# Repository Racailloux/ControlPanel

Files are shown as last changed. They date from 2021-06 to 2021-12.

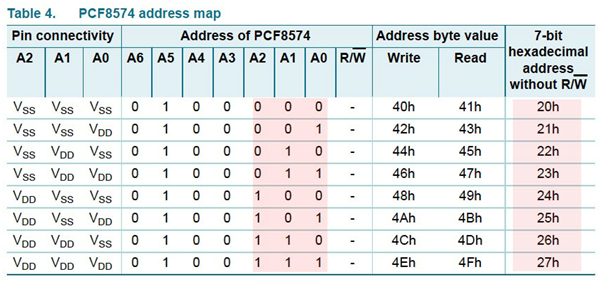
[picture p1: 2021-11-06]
Arduino/PCF8574_Addressing.png

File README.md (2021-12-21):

# Black Otters Control Panel






<br><br>
[French Section Française](#french-section) - 
[English English Section](#english-section)
<br><br>

<p align="center">Control Panel</p>

# French section

## Introduction

Ceci est un projet de panneau de contrôle personnalisé développé pour la corporation de la [Black Otters](https://www.blackotters-corporation.com/) du jeu [Star Citizen](https://robertsspaceindustries.com/star-citizen).

## Contenu

### Boitier imprimé 3D
* Modèles en 3D au format Fusion 360
* Fichiers STL exportés en STL

### Contrôles
Multiples contrôles optimisés pour l'utilisation dans Star Citizen (multi rôles : Vol, Combat & Minage)
* 1 Axe pour la puissance du minage
* 1 codeur pour encoder for le niveau des gaz
* 39 Boutons :
  * Boutons rétroéclairés par LEDs avec la luminosité ajustable (le potentiomètre sur la droite du boitier contrôle la luminosité)
  * Code couleur des boutons : Rouge : Urgencesy / Jaune : Changement de mode / Blanc : Réinitialisation / Vert : Boutons spéciaux / Bleu : Boutons standards

### Autocollant
Un autocollant modèle au format SVG pour placer sous les contrôles sur la façade avant : Textes, logo, ...

### Logiciel
Programme pour Arduino Micro relié à 5 modules d'extension PCF8574
* Mode Joystick contrôlé par USB
* Gestion de l'axe et du codeur
* Entrée analogique pour contrôler l'éclairage  des LEDs en PWM

### Association des contrôles pour Star Citizen
 * Fichier d'association (Layout) des contrôles pour l'importation dans Star Citizen (Utile pour les utilisateurs au clavier/souris, La gestion de multiple joysticks nécessitant une configuration adaptée)

## Credits

### Libraires Arduino

[Libraire Joystick](https://github.com/MHeironimus/ArduinoJoystickLibrary) : Libraire Arduino pour simuler le comportement d'un Joystick .<br>
[Libraire PCF8574](https://github.com/xreef/PCF8574_library) : Libraire Arduino pour gérer les puces PCF8574.<br>

### Sources d'inspiration

[Custom Starcitizen control panels](https://robertsspaceindustries.com/community/citizen-spotlight/3330-Custom-Starcitizen-Control-Panels)<br>
[Star Citizen Custom Controller](https://shinythinks.com/project/star-citizen-custom-controller/)<br>
[MAXED - Custom Star Citizen hardware. mk1 prototype](https://www.reddit.com/r/starcitizen/comments/9jc5qt/maxed_custom_star_citizen_hardware_mk1_prototype/)<br>

# English section

## Introduction

This is a project for custom Control Panel developped for [Black Otters](https://www.blackotters-corporation.com/) corporation in the [Star Citizen](https://robertsspaceindustries.com/star-citizen) game.

## Contents

### 3D printed case
* Fusion 360 3D models
* Exported files in STL

### Controls
Multiple controls optimized for Star Citizen usage (multi roles : Flight, Fight & Mining)
* 1 Axis for mining power
* 1 encoder for Throttle
* 39 Buttons :
  * Backlight with led power adjustable (potentiometer on the right of the case controls the LEDs power)
  * color coded buttons : Red : Emergency / Yellow : Mode change / White : Reset / Green : Special buttons / Blue : Standard buttons

### Sticker
Template sticker in SVG to be placed below front panel controls : Texts, logo, ...

### Software
Program of arduino Micro with 5 extension PCF8574 modules
* USB Controlled Joystick mode
* Encoder & Axis management
* Analog input to control PWM lighting level of LEDs

### Star Citizen Layout
 * Layout of the control panel to be imported in Star Citizen (for keyboard/mouse users only, multiple joysticks need a specific configuration)

## Credits

### Arduino Libraries

[Joystick Library](https://github.com/MHeironimus/ArduinoJoystickLibrary) : Arduino library to simulate a Joystick behavior.<br>
[PCF8574 Library](https://github.com/xreef/PCF8574_library) : Arduino Library to manage PCF8574 chipset.<br>
[Tools40](https://github.com/IndustrialShields/arduino-Tools40) : Arduino libraries used for debounce features.<br>

### Inspiration sources

[Custom Starcitizen control panels](https://robertsspaceindustries.com/community/citizen-spotlight/3330-Custom-Starcitizen-Control-Panels)<br>
[Star Citizen Custom Controller](https://shinythinks.com/project/star-citizen-custom-controller/)<br>
[MAXED - Custom Star Citizen hardware. mk1 prototype](https://www.reddit.com/r/starcitizen/comments/9jc5qt/maxed_custom_star_citizen_hardware_mk1_prototype/)<br>

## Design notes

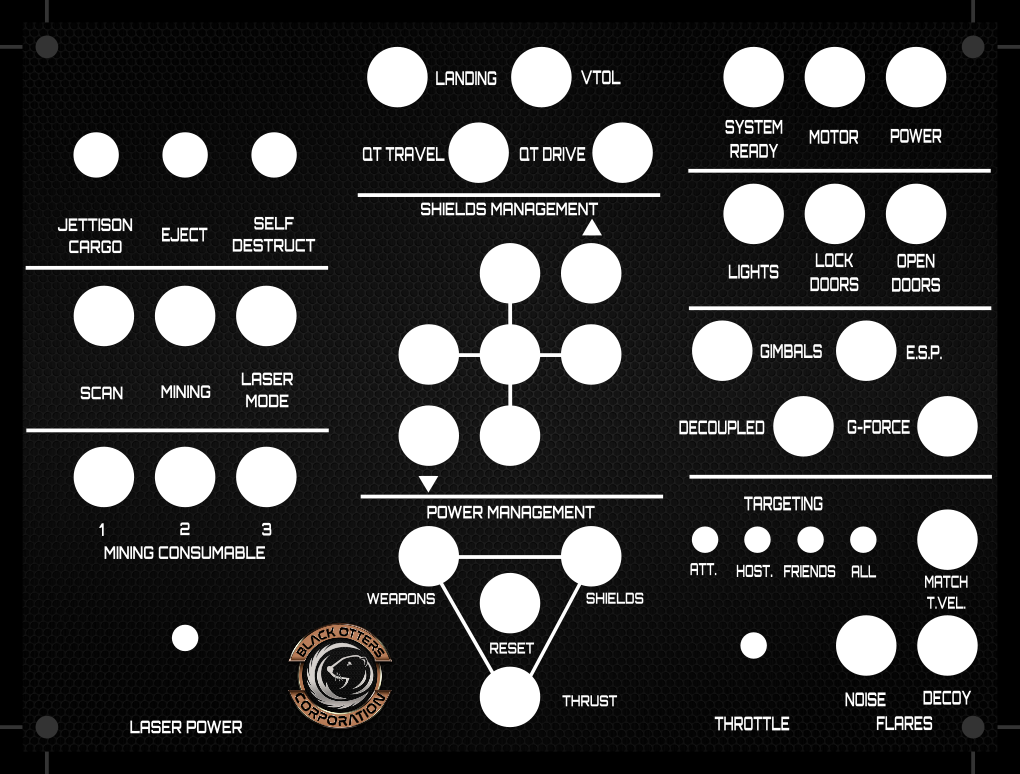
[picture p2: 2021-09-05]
Front Sticker/Front Sticker.png

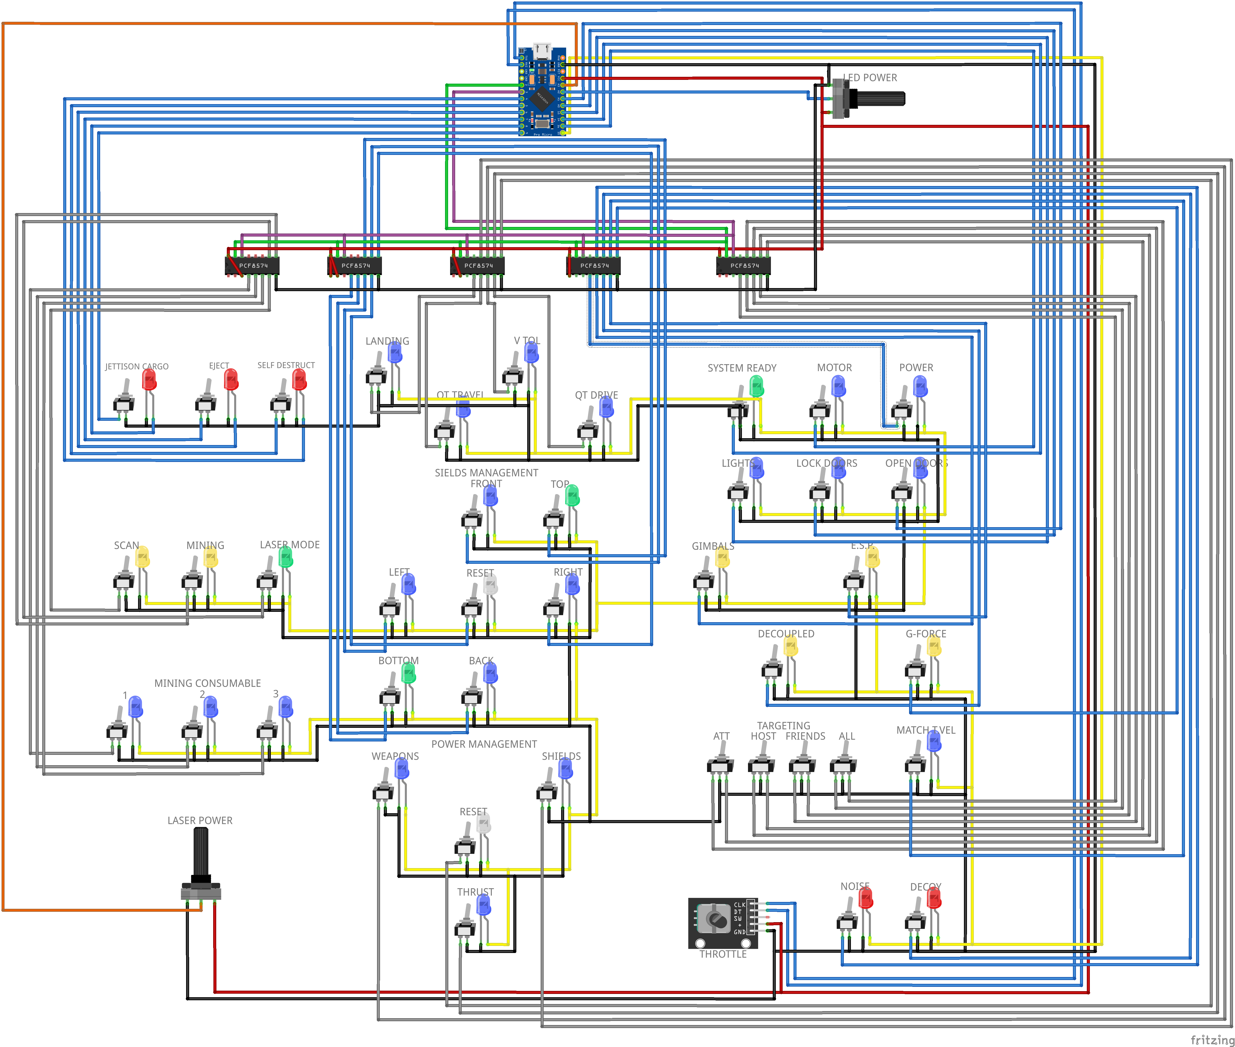
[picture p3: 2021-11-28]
Electrical diagrams/Electrical diagrams.png

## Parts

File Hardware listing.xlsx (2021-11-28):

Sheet: Nomenclature FR
Produits | Référence | Prix Unitaire | Quantité | Ports | Prix Total
Arduino micro | AliExpress (https://fr.aliexpress.com/item/1348800135.html) | 3.37 € | 1 | 2.50 € | 5.87 €
Carte d'extension PCF8574 | AliExpress (https://fr.aliexpress.com/item/32353277284.html) | 0.60 € | 5 | 2.85 € | 5.85 €
Bouton poussoir métal illuminé Bleu 16mm | AliExpress (https://fr.aliexpress.com/item/32972808322.html) | 0.95 € | 20 | 5.00 € | 24.00 €
Bouton poussoir métal illuminé Blanc 16mm | AliExpress | 0.95 € | 2 | 2.57 € | 4.47 €
Bouton poussoir métal illuminé Vert 16mm | AliExpress | 0.95 € | 4 | 2.84 € | 6.64 €
Bouton poussoir métal illuminé Jaune 16mm | AliExpress | 0.95 € | 6 | 3.14 € | 8.84 €
Bouton poussoir métal illuminé Rouge 16mm | AliExpress | 0.95 € | 2 | 2.57 € | 4.47 €
Inter (on)-off-(on) | AliExpress (https://fr.aliexpress.com/item/4000512396094.html) | 0.95 € | 4 | 2.54 € | 6.34 €
Interrupteur à capot | AliExpress (https://fr.aliexpress.com/item/32830627397.html) | 1.39 € | 3 | 4.11 € | 8.28 €
Codeur rotatif | AliExpress (https://fr.aliexpress.com/item/33041814942.html) | 0.38 € | 1 | 3.26 € | 3.64 €
Potentiomètre 10k | AliExpress | 0.56 € | 2 | 0.00 € | 1.12 €
Bouton potentiomètre 25mm (codeur) | AliExpress (https://fr.aliexpress.com/item/32749196628.html) | 1.48 € | 1 | 1.23 € | 2.71 €
Bouton potentiomètre 29mm (potentiomètre) | AliExpress (https://fr.aliexpress.com/item/32919900747.html) | 0.31 € | 1 | 1.12 € | 1.43 €
Câbles dupont 40cm F2F | AliExpress (https://fr.aliexpress.com/item/32965923603.html) | 1.56 € | 2 | 2.39 € | 5.51 €
Fil 22AWG | Amazon (https://www.amazon.fr/dp/B08BPBPBWT/) | 0.28 € | 8 | 0.00 € | 2.27 €
Filament PLA noir | SOVB3D (https://www.sovb3d.fr/pla-175mm-standard-1kg/108-fil-pla-noir-175mm-1kg.html) | 25.45 € | 0.5 |  | 12.72 €
Vis M3 x8mm | Aliexpress (https://fr.aliexpress.com/item/32810872544.html) | 0.02 € | 8 | 1.77 € | 1.93 €
Vis M3 x12mm | Aliexpress | 0.08 € | 8 | 1.77 € | 2.40 €
Autocollant | Amazon (https://www.amazon.fr/dp/B00PFW4K7C/) | 2.00 € | 1 |  | 2.00 €
Encre | Amazon (https://www.amazon.fr/dp/B000NOSAXW/) | 23.99 € | 0.5 |  | 11.99 €
Laque brillante | Amazon (https://www.amazon.fr/gp/product/B00AF09NK8/) | 11.50 € | 0.05 |  | 0.58 €
Antidérapants | Amazon (https://www.amazon.fr/dp/B07C9XKDDK/) | 0.21 € | 4 |  | 0.84 €
 |  |  |  | TOTAL (est.) | 123.90 €

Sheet: Nomenclature EN
Protduct | Reference | Unit price | Quantity | Shipping | Total price
Arduino micro | AliExpress (https://fr.aliexpress.com/item/1348800135.html) | 3.37 € | 1 | 2.50 € | 5.87 €
PCF8574 extension board | AliExpress (https://fr.aliexpress.com/item/32353277284.html) | 0.60 € | 5 | 2.85 € | 5.85 €
Illuminated metal pushbutton Blue 16mm | AliExpress (https://fr.aliexpress.com/item/32972808322.html) | 0.95 € | 20 | 5.00 € | 24.00 €
Illuminated metal pushbutton White 16mm | AliExpress | 0.95 € | 2 | 2.57 € | 4.47 €
Illuminated metal pushbutton Green 16mm | AliExpress | 0.95 € | 4 | 2.84 € | 6.64 €
Illuminated metal pushbutton Yellow 16mm | AliExpress | 0.95 € | 6 | 3.14 € | 8.84 €
Illuminated metal pushbutton Red 16mm | AliExpress | 0.95 € | 2 | 2.57 € | 4.47 €
Inter (on)-off-(on) | AliExpress (https://fr.aliexpress.com/item/4000512396094.html) | 0.95 € | 4 | 2.54 € | 6.34 €
Protected switch | AliExpress (https://fr.aliexpress.com/item/32830627397.html) | 1.39 € | 3 | 4.11 € | 8.28 €
Codeur rotatif | AliExpress (https://fr.aliexpress.com/item/33041814942.html) | 0.38 € | 1 | 3.26 € | 3.64 €
Potentiometer 10k | AliExpress | 0.56 € | 2 | 0.00 € | 1.12 €
Potentiometer button 25mm (encoder) | AliExpress (https://fr.aliexpress.com/item/32749196628.html) | 1.48 € | 1 | 1.23 € | 2.71 €
Potentiometer button 29mm (potentiometer) | AliExpress (https://fr.aliexpress.com/item/32919900747.html) | 0.31 € | 1 | 1.12 € | 1.43 €
Dupont cables 40cm F2F | AliExpress (https://fr.aliexpress.com/item/32965923603.html) | 1.56 € | 2 | 2.39 € | 5.51 €
22AWG wires | Amazon (https://www.amazon.fr/dp/B08BPBPBWT/) | 0.28 € | 8 | 0.00 € | 2.27 €
black PLA filament | SOVB3D (https://www.sovb3d.fr/pla-175mm-standard-1kg/108-fil-pla-noir-175mm-1kg.html) | 25.45 € | 0.5 |  | 12.72 €
M3 screw x8mm | Aliexpress (https://fr.aliexpress.com/item/32810872544.html) | 0.02 € | 8 | 1.77 € | 1.93 €
M3 screw x12mm | Aliexpress | 0.08 € | 8 | 1.77 € | 2.40 €
Sticker | Amazon (https://www.amazon.fr/dp/B00PFW4K7C/) | 2.00 € | 1 |  | 2.00 €
Ink | Amazon (https://www.amazon.fr/dp/B000NOSAXW/) | 23.99 € | 0.5 |  | 11.99 €
glossy lacquer | Amazon (https://www.amazon.fr/gp/product/B00AF09NK8/) | 11.50 € | 0.05 |  | 0.58 €
Non-slip | Amazon (https://www.amazon.fr/dp/B07C9XKDDK/) | 0.21 € | 4 |  | 0.84 €
 |  |  |  | TOTAL (est.) | 123.90 €

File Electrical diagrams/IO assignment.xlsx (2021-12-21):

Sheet: IO Assignment
Hardware | Input | Pin | I/O | Type | SC command | Joystick
Arduino Micro | GND | GND | 0V |  |  | -
 | 5V | VCC | 5V |  |  | -
 | 0 | RX1 | Input | Encoder CLK | Throttle Increase | 1
 | 1 | TX0 | Input | Encoder DT | Throttle Decrease | 2
 | SDA | 2 | SDA |  |  | -
 | SCL | 3 | SCL |  |  | -
 | 4 | 4 | Output | Protected switch | Self-destruct LED | led
 | 5 | 5 | Input | Protected switch | Self-destruct INTER | 3
 | 6 | 6 | Output | Protected switch | Eject LED | led
 | 7 | 7 | Input | Protected switch | Eject INTER | 4
 | 8 | 8 | Output | Protected switch | Jettison Cargo LED | led
 | 9 | 9 | Input | Protected switch | Jettison Cargo INTER | 5
 | 10 | 10 | PWM | LEDs | PWM for LEDs power | led
 | 16 | 16 | Input | Momentary switch blue | Motor on/off | 7
 | 14 | 14 | Input | Momentary switch green | System ready | 8
 | 15 | 15 | Input | Momentary switch blue | Open doors | 9
 | 18 | A0 | Input | Momentary switch blue | Lock doors | 10
 | 19 | A1 | Input | Momentary switch blue | Lights | 11
 | 20 | A2 | Analog | Potentiometer 10k | Power level LEDs | led
 | A3 | A3 | Analog | Potentiometer 10k | Laser power | Throttle
PCF8574 Addr : 0x20 | P0 |  | Input | Inter (on)-off-(on) | Target all (Back) | hat1-down
 | P1 |  | Input | Inter (on)-off-(on) | Target all (Forward) | hat1-up
 | P2 |  | Input | Inter (on)-off-(on) | Target friends (Back) | hat1-left
 | P3 |  | Input | Inter (on)-off-(on) | Target friends (Forward) | hat1-right
 | P4 |  | Input | Inter (on)-off-(on) | Target ennemis (Back) | hat2-down
 | P5 |  | Input | Inter (on)-off-(on) | Target ennemis (Forward) | hat2-up
 | P6 |  | Input | Inter (on)-off-(on) | Target hostiles (Back) | hat2-left
 | P7 |  | Input | Inter (on)-off-(on) | Target hostiles (Forward) | hat2-right
 | PINT |  | Input
PCF8574 Addr : 0x21 | P0 |  | Input | Momentary switch blue | Power on/off | 6
 | P1 |  | Input | Momentary switch yellow | Cycle Gimbal Assist / Standard Gimbal / Gimbal Lock modes | 12
 | P2 |  | Input | Momentary switch yellow | Decoupled | 13
 | P3 |  | Input | Momentary switch yellow | E.S.P. | 14
 | P4 |  | Input | Momentary switch yellow | G-force | 15
 | P5 |  | Input | Momentary switch blue | Match target velocity | 16
 | P6 |  | Input | Momentary switch red | Decoy - Launch Burst (tap) | 17
 | P7 |  | Input | Momentary switch red | Noise - Deploy (tap) | 18
 | PINT |  | Input
PCF8574 Addr : 0x22 | P0 |  | Input | Momentary switch blue | Landing | 19
 | P1 |  | Input | Momentary switch blue | QT Travel | 20
 | P2 |  | Input | Momentary switch blue | VTOL | 21
 | P3 |  | Input | Momentary switch blue | QT Drive | 22
 | P4 |  | Input | Momentary switch white | Power Reset | 23
 | P5 |  | Input | Momentary switch blue | Power Thrust | 24
 | P6 |  | Input | Momentary switch blue | Power Weapon | 25
 | P7 |  | Input | Momentary switch blue | Power Shield | 26
 | PINT |  | Input
PCF8574 Addr : 0x23 | P0 |  | Input | Momentary switch green | Shield raise level bottom | 27
 | P1 |  | Input | Momentary switch blue | Shield raise level back | 28
 | P2 |  | Input | Momentary switch blue | Shield raise level left | 29
 | P3 |  | Input | Momentary switch white | Shield reset levels | 30
 | P4 |  | Input | Momentary switch blue | Shield raise level right | 31
 | P5 |  | Input | Momentary switch blue | Shield raise level front | 32
 | P6 |  | Input | Momentary switch green | Shield raise level top | 33
 | P7 |  | Input
 | PINT |  | Input
PCF8574 Addr : 0x24 | P0 |  | Input | Momentary switch blue | Activate consumable (Slot1) | 34
 | P1 |  | Input | Momentary switch blue | Activate consumable (Slot2) | 35
 | P2 |  | Input | Momentary switch blue | Activate consumable (Slot3) | 36
 | P3 |  | Input | Momentary switch yellow | Scan | 37
 | P4 |  | Input | Momentary switch yellow | Mining | 38
 | P5 |  | Input | Momentary switch yellow | Laser mode | 39
 | P6 |  | Input
 | P7 |  | Input
 | PINT |  | Input

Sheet: Affectations IO
Matériel | Entrée | Pin | I/O | Type | Commande SC | Joystick
Arduino Micro | GND | GND | 0V |  |  | -
 | 5V | VCC | 5V |  |  | -
 | 0 | RX1 | Input | Codeur CLK | Throttle Increase | 1
 | 1 | TX0 | Input | Codeur DT | Throttle Decrease | 2
 | SDA | 2 | SDA |  |  | -
 | SCL | 3 | SCL |  |  | -
 | 4 | 4 | Output | Interrupteur à capot | Self-destruct LED | led
 | 5 | 5 | Input | Interrupteur à capot | Self-destruct INTER | 3
 | 6 | 6 | Output | Interrupteur à capot | Eject LED | led
 | 7 | 7 | Input | Interrupteur à capot | Eject INTER | 4
 | 8 | 8 | Output | Interrupteur à capot | Jettison Cargo LED | led
 | 9 | 9 | Input | Interrupteur à capot | Jettison Cargo INTER | 5
 | 10 | 10 | PWM | LEDs | PWM pour puissance LEDs | led
 | 16 | 16 | Input | BP illuminé Bleu | Moteur on/off | 7
 | 14 | 14 | Input | BP illuminé Vert | System ready | 8
 | 15 | 15 | Input | BP illuminé Bleu | Lights | 9
 | 18 | A0 | Input | BP illuminé Bleu | Lock doors | 10
 | 19 | A1 | Input | BP illuminé Bleu | Open doors | 11
 | 20 | A2 | Analog | Potentiomètre 10k | Entrée puissance LEDs | led
 | A3 | A3 | Analog | Potentiomètre 10k | Laser power | Throttle
PCF8574 Addr : 0x20 | P0 |  | Input | Inter (on)-off-(on) | Ciblage tous (Back) | hat1-down
 | P1 |  | Input | Inter (on)-off-(on) | Ciblage tous (Forward) | hat1-up
 | P2 |  | Input | Inter (on)-off-(on) | Ciblage alliés (Back) | hat1-left
 | P3 |  | Input | Inter (on)-off-(on) | Ciblage alliés (Forward) | hat1-right
 | P4 |  | Input | Inter (on)-off-(on) | Ciblage ennemis (Back) | hat2-down
 | P5 |  | Input | Inter (on)-off-(on) | Ciblage ennemis (Forward) | hat2-up
 | P6 |  | Input | Inter (on)-off-(on) | Ciblage attaquants (Back) | hat2-left
 | P7 |  | Input | Inter (on)-off-(on) | Ciblage attaquants (Forward) | hat2-right
 | PINT |  | Input
PCF8574 Addr : 0x21 | P0 |  | Input | BP illuminé Bleu | Power on/off | 6
 | P1 |  | Input | BP illuminé Jaune | Cycle Gimbal Assist / Standard Gimbal / Gimbal Lock modes | 12
 | P2 |  | Input | BP illuminé Jaune | Decoupled | 13
 | P3 |  | Input | BP illuminé Jaune | E.S.P. | 14
 | P4 |  | Input | BP illuminé Jaune | G-force | 15
 | P5 |  | Input | BP illuminé Bleu | Match target velocity | 16
 | P6 |  | Input | BP illuminé Rouge | Decoy - Launch Burst (tap) | 17
 | P7 |  | Input | BP illuminé Rouge | Noise - Deploy (tap) | 18
 | PINT |  | Input
PCF8574 Addr : 0x22 | P0 |  | Input | BP illuminé Bleu | Landing | 19
 | P1 |  | Input | BP illuminé Bleu | QT Travel | 20
 | P2 |  | Input | BP illuminé Bleu | VTOL | 21
 | P3 |  | Input | BP illuminé Bleu | QT Drive | 22
 | P4 |  | Input | BP illuminé Blanc | Power Reset | 23
 | P5 |  | Input | BP illuminé Bleu | Power Thrust | 24
 | P6 |  | Input | BP illuminé Bleu | Power Weapon | 25
 | P7 |  | Input | BP illuminé Bleu | Power Shield | 26
 | PINT |  | Input
PCF8574 Addr : 0x23 | P0 |  | Input | BP illuminé Vert | Shield raise level bottom | 27
 | P1 |  | Input | BP illuminé Bleu | Shield raise level back | 28
 | P2 |  | Input | BP illuminé Bleu | Shield raise level left | 29
 | P3 |  | Input | BP illuminé Blanc | Shield reset levels | 30
 | P4 |  | Input | BP illuminé Bleu | Shield raise level right | 31
 | P5 |  | Input | BP illuminé Bleu | Shield raise level front | 32
 | P6 |  | Input | BP illuminé Vert | Shield raise level top | 33
 | P7 |  | Input
 | PINT |  | Input
PCF8574 Addr : 0x24 | P0 |  | Input | BP illuminé Bleu | Activate consumable (Slot1) | 34
 | P1 |  | Input | BP illuminé Bleu | Activate consumable (Slot2) | 35
 | P2 |  | Input | BP illuminé Bleu | Activate consumable (Slot3) | 36
 | P3 |  | Input | BP illuminé Jaune | Scan | 37
 | P4 |  | Input | BP illuminé Jaune | Mining | 38
 | P5 |  | Input | BP illuminé Jaune | Laser mode | 39
 | P6 |  | Input
 | P7 |  | Input
 | PINT |  | Input

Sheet: Mapping des contrôles
Commande SC | Joystick
Throttle Increase | 1
Throttle Decrease | 2
Self-destruct INTER | 3
Eject INTER | 4
Jettison Cargo INTER | 5
Power on/off | 6
Moteur on/off | 7
System ready | 8
Lights | 9
Lock doors | 10
Open doors | 11
Cycle Gimbal Assist / Standard Gimbal / Gimbal Lock modes | 12
Decoupled | 13
E.S.P. | 14
G-force | 15
Match target velocity | 16
Decoy - Launch Burst (tap) | 17
Noise - Deploy (tap) | 18
Landing | 19
QT Travel | 20
VTOL | 21
QT Drive | 22
Power Reset | 23
Power Thrust | 24
Power Weapon | 25
Power Shield | 26
Shield raise level bottom | 27
Shield raise level back | 28
Shield raise level left | 29
Shield reset levels | 30
Shield raise level right | 31
Shield raise level front | 32
Shield raise level top | 33
Activate consumable (Slot1) | 34
Activate consumable (Slot2) | 35
Activate consumable (Slot3) | 36
Scan | 37
Mining | 38
Laser mode | 39
Laser power | Throttle
Ciblage tous (Back) | hat1-down
Ciblage tous (Forward) | hat1-up
Ciblage alliés (Back) | hat1-left
Ciblage alliés (Forward) | hat1-right
Ciblage ennemis (Back) | hat2-down
Ciblage ennemis (Forward) | hat2-up
Ciblage attaquants (Back) | hat2-left
Ciblage attaquants (Forward) | hat2-right

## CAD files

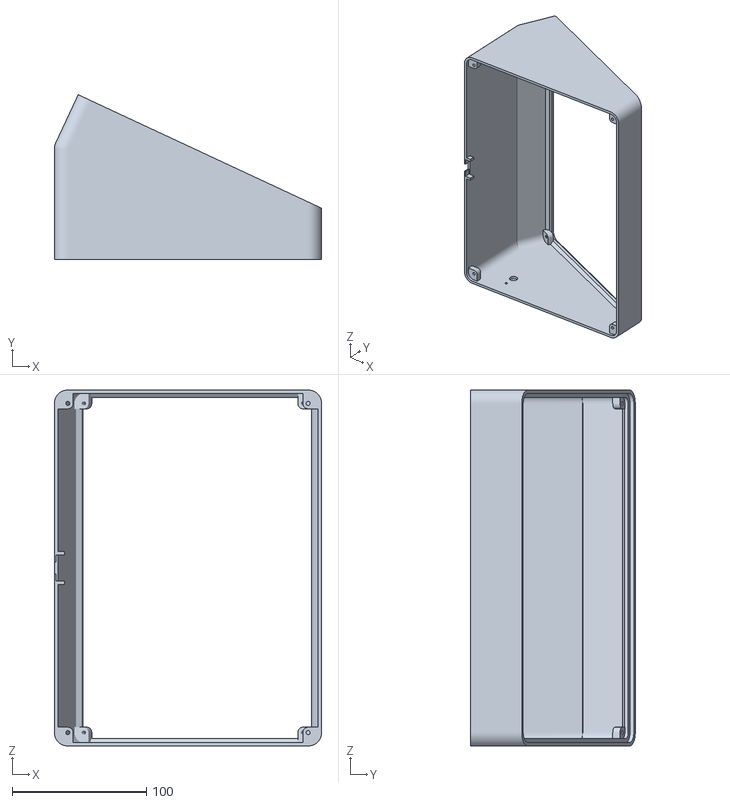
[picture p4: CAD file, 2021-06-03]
3D housing/CP-BO Side v19.stl
199.0 x 122.5 x 265.0

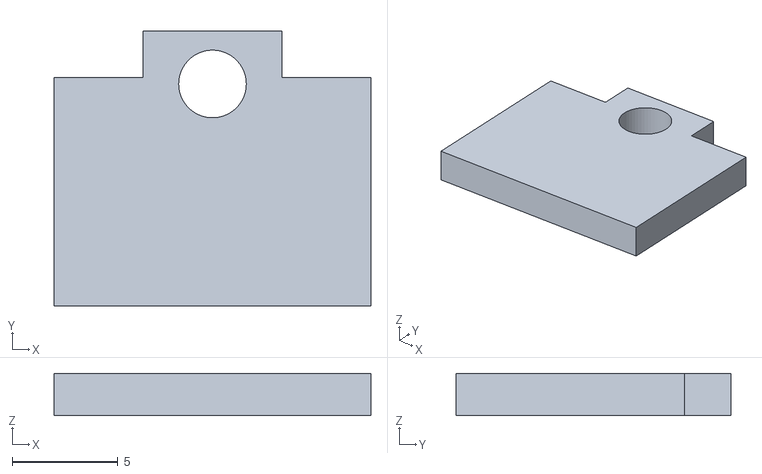
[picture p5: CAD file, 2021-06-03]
3D housing/CP-BO PCF8574 locker v2.stl
15.0 x 13.0 x 2.00

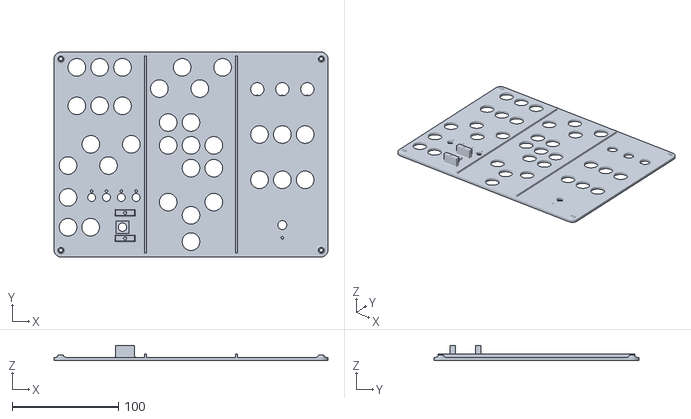
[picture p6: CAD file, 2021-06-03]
3D housing/CP-BO Front v3.stl
257.8 x 192.8 x 14.0

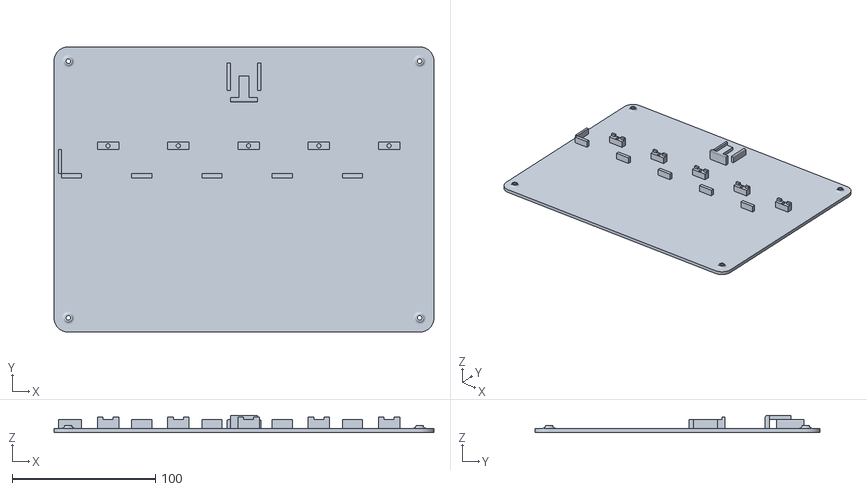
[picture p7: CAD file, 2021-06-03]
3D housing/CP-BO Back v15.stl
265.0 x 199.0 x 12.0

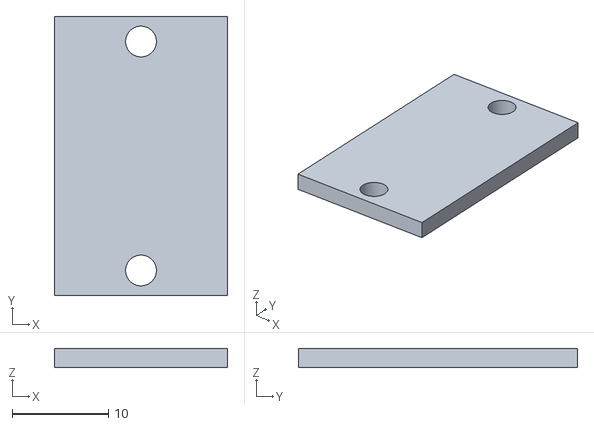
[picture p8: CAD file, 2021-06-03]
3D housing/CP-BO Encoder locker v1.stl
18.0 x 29.0 x 2.00

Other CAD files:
3D housing/CP-BO Back v15.f3d
3D housing/CP-BO Encoder locker v1.f3d
3D housing/CP-BO Front v3.f3d
3D housing/CP-BO PCF8574 locker v2.f3d
3D housing/CP-BO Side v19.f3d

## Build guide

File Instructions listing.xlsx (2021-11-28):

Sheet: Instructions FR
Etape | Instructions
Impression 3D du boitier | Imprimer le fond, le contours, la façade, 1 cale pour le codeur et 5 cales pour PCF8574
Adresser les cartes PCF8574 | Régler les adresses des 5 cartes PCF8574 de 0x20 à 0x24
Installer les cartes | Installer les cartes 5 cartes PCF8574 et viser leurs cales (vis M3x8) (redresser les pins de la première carte). Installer la carte arduino micro.
Assembler le boitier | Visser le fond avec le contour à l'aide de 4 vis M3x12.
Encollez les cartes | A la colle à chaud, bloquez les cartes arduino et PCF8574 afin d'éviter qu'elles bougent et ne fassent de bruit.
Vernir l'étiquette | Passer une bombe de vernis (brillant ou mat) sur l'étiquette, en veillant à ne pas la toucher avec les doigts, ni faite de dépôt de vernis.
Découper et coller l'étiquette sur la façade | Aligner les trous des 4 vis de la façade pour coller l'étiquette sur celle-ci.
Replier et renforcer les bords de l'étiquette | Replier les bords de l'étiquette sur le dos de la façace et renforcer avec un scotch assez fort (scotch d'électricien déformable, mais suffisant)
Installer les contrôles | Installer les contrôles (boutons, potentiomètres et codeurs) sur la façade (attention au serrage, ni trop fort, ni trop faible) en alignant les pins des boutons en vu des soudures.
Souder les lignes de masse et de PWM des leds | Souder les lignes de masse (noir) et les lignes de PWM (rouge ou blanc) sur le dos de la façade.
Souder le potentiomètre pour l'analogique PWM | Souder le potentiomètre au contrôle le plus en bas à droite de la façade et à des fisl en connecteurs Dupont femelle pour relier à la puissance et à l'entrée analogique.
Souder par nappes les contrôles | Couper une extrémité des nappes Dupont en 40cm pour les souder aux contrôles en suivant l'ordre du schéma électrique.
Relier les nappes aux cartes | Relier les nappes aux cartes en suivant l'ordre du schéma électrique.
Fermer le boitier | Installer la façade à l'aide de 4 vis M3x12
Injecter le programme arduino | Connecter l'arduino à l'aide d'un câble micro USB à votre PC. Installer l'environnement de développement et injecter le programme 'ControlPanel.ino'.

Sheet: Instructions EN
Etape | Instructions
Printing the 3D housing | Print the base, the surround, the front, 1 wedge for encoder and 5 wedges for PCF8574
Adress the PCF8574 boards | Set the addresses of the 5 PCF8574 cards from 0x20 to 0x24
Install all boards | Install the 5 PCF8574 boards and screw their wedges (M3x8 screws) (Fold the pins of the first board). Install the arduino micro card.
Assembly of the housing | Screw the base with the surround using 4x M3x12 screws.
Englue the boards | With hot glue, lock the boards arduino & PCF8574 to avoid movements and noises.
Vanish the sticker | Apply a spray of varnish (gloss or mat) on the sticker, taking care not to touch it with your fingers, or make varnish deposit.
Cut the borders & stick the sticker | Align the holes of the 4 screws on the front panel to stick the sticker on it.
Fold and reinforce the edges of the sticker | Fold the edges of the sticker on the back of the front panel and reinforce them with a fairly strong tape (electrician's tape too deformable, but sufficient)
Install the controls | Install the controls (buttons, potentiometers and encoders) on the front panel (be careful with tightening, neither too strong nor too weak) by aligning the pins of the buttons in view of soldering.
Solder the ground and leds PWM lines | Solder the ground lines (black) and the PWM lines (red or white) on the back of the front panel.
Solder the potentiometer for PWM analog | Solder the potentiometer to the lower right control of the front panel and to female Dupont connectors wires to connect to the power and to the analog input.
Solder the controls | Cut one end of the 40cm Dupont cables to solder them to the controls following the order of the electrical diagram.
Connect the ribbons to the cards | Connect the cables to the boards following the order of the electrical diagram.
Close the housing | Install the front panel using 4x M3x12 screws.
Inject the arduino program | Connect the arduino using a micro USB cable to your PC. Install the development environment and inject the 'ControlPanel.ino' program.

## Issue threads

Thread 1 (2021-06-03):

Réglage des boucliers & de la puissance

Nemehy, 2021-06-03:
Lorsqu'on appuie sur un bouton pour régler la puissance (par exemple), ça augmente deux par deux.
Il faudrait filtrer l'appuie des touches pour gérer le rebond.

Racailloux, 2021-10-08:
Problème plus présent depuis la 3.14.

Closed 2021-10-08.

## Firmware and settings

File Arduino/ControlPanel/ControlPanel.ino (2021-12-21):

/*
   Control Panel for Star Citizen - Joystick version

   CopyRight 2021 - Black Otters
   Authors : Racailloux - Nemehy

   External libraries references :
   Joystick : https://github.com/MHeironimus/ArduinoJoystickLibrary
   PCF8574  : https://github.com/xreef/PCF8574_library

   TODO :
   * Managing outputs for "fatal leds"
*/
#include <Joystick.h>
#include <PCF8574.h>
#include <Filter.h>

// Handle serial messages only if debug is active
#define DEBUG   0


//////////////////////////////////////////////////////////////////////////////////////////////
// Constant declarations
// Backlight
const int PIN_PWM_BACKLIGHT = 10;
const int PIN_ANA_BACKLIGHT = A2;
// Mining laser power
const int PIN_MINING_POWER  = A3;
// Rotary encoder
const int PIN_ENC_CLK      = 0;
const int PIN_ENC_DT       = 1;
const int ENC_STEP_NR      = 20; // Number of increments of the encoder
const int ENC_STRIKE_TIMER = 50; // Timer before button rise down for encoder movement in ms
// Arduino inputs
const int LED_SELF_DESTRUCT  = 4;
const int PIN_SELF_DESTRUCT  = 5;
const int LED_EJECT          = 6;
const int PIN_EJECT          = 7;
const int LED_JETTISON_CARGO = 8;
const int PIN_JETTISON_CARGO = 9;
const int PIN_MOTOR          = 16;
const int PIN_SYSTEM_READY   = 14;
const int PIN_LIGHTS         = 15;
const int PIN_LOCK_DOORS     = 18;
const int PIN_OPEN_DOORS     = 19;


//////////////////////////////////////////////////////////////////////////////////////////////
// Input statement memorization variables
// Backlight
byte backlight_level = 0;
// Rotary encoder
int  state_enc_clk = LOW;
long enc_position = -1;  // will change to "0" at startup
// Arduino inputs
byte state_self_destruct  = false;
byte state_eject          = false;
byte state_jettison_cargo = false;
byte state_motor          = false;
byte state_system_ready   = false;
byte state_lights         = false;
byte state_lock_doors     = false;
byte state_open_doors     = false;
// PCF8574 @addr=20
int state_target_hat1 = JOYSTICK_HATSWITCH_RELEASE;
int state_target_hat2 = JOYSTICK_HATSWITCH_RELEASE;
// PCF8574 @addr=21
byte state_power      = false;
byte state_gimbal     = false;
byte state_decoupled  = false;
byte state_esp        = false;
byte state_gforce     = false;
byte state_match_tvel = false;
byte state_decoy      = false;
byte state_noise      = false;
// PCF8574 @addr=22
byte state_power_shield = false;
byte state_power_weapon = false;
byte state_power_thrust = false;
byte state_power_reset  = false;
byte state_qt_drive     = false;
byte state_vtol         = false;
byte state_qt_travel    = false;
byte state_landing      = false;
// PCF8574 @addr=23
byte state_shield_top    = false;
byte state_shield_front  = false;
byte state_shield_right  = false;
byte state_shield_reset  = false;
byte state_shield_left   = false;
byte state_shield_back   = false;
byte state_shield_bottom = false;
// PCF8574 @addr=24
byte state_scan         = false;
byte state_mining       = false;
byte state_laser_mode   = false;
byte state_consumable_1 = false;
byte state_consumable_2 = false;
byte state_consumable_3 = false;


//////////////////////////////////////////////////////////////////////////////////////////////
// Timers declaration
unsigned long enc_timer;
DigitalFilter<200> filterSelfDestruct;
DigitalFilter<200> filterEject;
DigitalFilter<200> filterJettisonCargo;

  
//////////////////////////////////////////////////////////////////////////////////////////////
// Libraries objects declaration

// Joystick declaration
Joystick_ Joystick(
  JOYSTICK_DEFAULT_REPORT_ID, // hidReportId
  JOYSTICK_TYPE_JOYSTICK,     // joystickType. Supported values: JOYSTICK_TYPE_JOYSTICK or 0x04 - Joystick / JOYSTICK_TYPE_GAMEPAD or 0x05 - Gamepad / JOYSTICK_TYPE_MULTI_AXIS or 0x08 - Multi-axis Controller
  39,                         // buttonCount
  2,                          // hatSwitchCount
  false,                      // includeXAxis
  false,                      // includeYAxis
  true,                       // includeZAxis => Mining laser power
  false,                      // includeRxAxis
  false,                      // includeRyAxis
  false,                      // includeRzAxis
  false,                      // includeRudder
  false,                      // includeThrottle
  false,                      // includeAccelerator
  false,                      // includeBrake
  false);                     // includeSteering

// I²C declarations
PCF8574 PCF20(0x20);
PCF8574 PCF21(0x21);
PCF8574 PCF22(0x22);
PCF8574 PCF23(0x23);
PCF8574 PCF24(0x24);


//////////////////////////////////////////////////////////////////////////////////////////////
// Initialization of the board
void setup()
{
  // power-up safety delay
  delay(1000);
  DebugInit();
  delay(1000);

  // Backlight management
  analogWrite(PIN_PWM_BACKLIGHT, backlight_level);
  
  // Initialize Joystick mode
  Joystick.begin();
  
  // Prepare analog input for Mining laser power
  Joystick.setZAxisRange(0,1024);

  // Prepare rotary encoder
  pinMode(PIN_ENC_CLK, INPUT_PULLUP);
  pinMode(PIN_ENC_DT, INPUT_PULLUP);
  
  // Prepare I/O from Arduino
  pinMode(PIN_SELF_DESTRUCT,  INPUT_PULLUP);
  pinMode(PIN_EJECT,          INPUT_PULLUP);
  pinMode(PIN_JETTISON_CARGO, INPUT_PULLUP);
  
  pinMode(PIN_MOTOR,          INPUT_PULLUP);
  pinMode(PIN_SYSTEM_READY,   INPUT_PULLUP);
  pinMode(PIN_LIGHTS,         INPUT_PULLUP);
  pinMode(PIN_LOCK_DOORS,     INPUT_PULLUP);
  pinMode(PIN_OPEN_DOORS,     INPUT_PULLUP);
  // Prepare PCF8574 @addr=20
  Joystick.setHatSwitch(0, state_target_hat1);
  Joystick.setHatSwitch(1, state_target_hat2);
  // Prepare PCF8574
  PreparePcfInputs(&PCF20);
  PreparePcfInputs(&PCF21);
  PreparePcfInputs(&PCF22);
  PreparePcfInputs(&PCF23);
  PreparePcfInputs(&PCF24);
  // Led management
  pinMode(LED_SELF_DESTRUCT,  OUTPUT);
  pinMode(LED_EJECT,          OUTPUT);
  pinMode(LED_JETTISON_CARGO, OUTPUT);
} // End of "setup"


//////////////////////////////////////////////////////////////////////////////////////////////
/// Main program cyclically called
void loop()
{  
  // Update backlight PWM level from Analog input
  int nAnaBackLight = analogRead(PIN_ANA_BACKLIGHT);
  int newBackLightLevel = (nAnaBackLight/4);
  if((newBackLightLevel < (backlight_level-1)) || (newBackLightLevel > (backlight_level+1)))
  {
    // Updating backlight level
    backlight_level = (nAnaBackLight/4);
    analogWrite(PIN_PWM_BACKLIGHT, backlight_level);
    DebugLn("New backlight level : " + String(backlight_level));
  }
  
  // Update analog axis for mining power
  Joystick.setZAxis(analogRead(PIN_MINING_POWER));
  
  // Rotary rotary encoder management
  EncoderManagement(PIN_ENC_CLK, PIN_ENC_DT, 0, 1);
  
  // Update buttons from Arduino
  UpdateBoardButton(PIN_SELF_DESTRUCT,  2, &state_self_destruct, &filterSelfDestruct);
  UpdateBoardButton(PIN_EJECT,          3, &state_eject, &filterEject);
  UpdateBoardButton(PIN_JETTISON_CARGO, 4, &state_jettison_cargo, &filterJettisonCargo);
  UpdateBoardButton(PIN_MOTOR,          6, &state_motor, NULL);
  UpdateBoardButton(PIN_SYSTEM_READY,   7, &state_system_ready, NULL);
  UpdateBoardButton(PIN_LIGHTS,         8, &state_lights, NULL);
  UpdateBoardButton(PIN_LOCK_DOORS,     9, &state_lock_doors, NULL);
  UpdateBoardButton(PIN_OPEN_DOORS,    10, &state_open_doors, NULL);

  // Update buttons from PCF8574 @addr=20
  PCF8574::DigitalInput di20 = PCF20.digitalReadAll();
  int nHat1 = JOYSTICK_HATSWITCH_RELEASE;
  if(!di20.p0) {nHat1 = 180;}
  else if(!di20.p1) {nHat1 = 360;}
  else if(!di20.p2) {nHat1 = 270;}
  else if(!di20.p3) {nHat1 = 90;}
  if (nHat1 != state_target_hat1)
  {
    Joystick.setHatSwitch(0, nHat1);
    state_target_hat1 = nHat1;
    DebugLn("Hat1=" + String(nHat1));
  }

  int nHat2 = JOYSTICK_HATSWITCH_RELEASE;
  if(!di20.p4) {nHat2 = 180;}
  else if(!di20.p5) {nHat2 = 360;}
  else if(!di20.p6) {nHat2 = 270;}
  else if(!di20.p7) {nHat2 = 90;}
  if (nHat2 != state_target_hat2)
  {
    Joystick.setHatSwitch(1, nHat2);
    state_target_hat2 = nHat2;
    DebugLn("Hat2=" + String(nHat2));
  }

  // Update buttons from PCF8574 @addr=21
  PCF8574::DigitalInput di21 = PCF21.digitalReadAll();
  UpdateButton(di21.p0,  5, &state_power);
  UpdateButton(di21.p1, 11, &state_gimbal);
  UpdateButton(di21.p2, 12, &state_decoupled);
  UpdateButton(di21.p3, 13, &state_esp);
  UpdateButton(di21.p4, 14, &state_gforce);
  UpdateButton(di21.p5, 15, &state_match_tvel);
  UpdateButton(di21.p6, 16, &state_decoy);
  UpdateButton(di21.p7, 17, &state_noise);
  
  // Update buttons from PCF8574 @addr=22
  PCF8574::DigitalInput di22 = PCF22.digitalReadAll();
  UpdateButton(di22.p0, 18, &state_power_shield);
  UpdateButton(di22.p1, 19, &state_power_weapon);
  UpdateButton(di22.p2, 20, &state_power_thrust);
  UpdateButton(di22.p3, 21, &state_power_reset);
  UpdateButton(di22.p4, 22, &state_qt_drive);
  UpdateButton(di22.p5, 23, &state_vtol);
  UpdateButton(di22.p6, 24, &state_qt_travel);
  UpdateButton(di22.p7, 25, &state_landing);
  
  // Update buttons from PCF8574 @addr=23
  PCF8574::DigitalInput di23 = PCF23.digitalReadAll();
  UpdateButton(di23.p0, 26, &state_shield_top);
  UpdateButton(di23.p1, 27, &state_shield_front);
  UpdateButton(di23.p2, 28, &state_shield_right);
  UpdateButton(di23.p3, 29, &state_shield_reset);
  UpdateButton(di23.p4, 30, &state_shield_left);
  UpdateButton(di23.p5, 31, &state_shield_back);
  UpdateButton(di23.p6, 32, &state_shield_bottom);
  
  // Update buttons from PCF8574 @addr=24
  PCF8574::DigitalInput di24 = PCF24.digitalReadAll();
  UpdateButton(di24.p0, 33, &state_scan);
  UpdateButton(di24.p1, 34, &state_mining);
  UpdateButton(di24.p2, 35, &state_laser_mode);
  UpdateButton(di24.p3, 36, &state_consumable_1);
  UpdateButton(di24.p4, 37, &state_consumable_2);
  UpdateButton(di24.p5, 38, &state_consumable_3);

} // End of "loop"


//////////////////////////////////////////////////////////////////////////////////////////////
// Local functions

// Generic button status update from I/O board
byte UpdateBoardButton(int SwitchPinNr, int JoyButtonNr, byte* PreviousState, DigitalFilter<200>* filter)
{
  int filtered;
  if(filter != NULL) {
    filtered = filter->update(digitalRead(SwitchPinNr));
  }
  else {filtered = digitalRead(SwitchPinNr);}
  
  UpdateButton(filtered, JoyButtonNr, PreviousState);
} // End of "UpdateButton"


// Generic button status update
byte UpdateButton(byte CurrentState, int JoyButtonNr, byte* PreviousState)
{
  if (CurrentState != *PreviousState)
  {
    Joystick.setButton(JoyButtonNr, !CurrentState);
    *PreviousState = CurrentState;
    DebugTxt("Button changed: " + String(JoyButtonNr));
    DebugLn(" to value " + String(CurrentState));
  }
} // End of "UpdateButton"


// Rotatory encoder management as 2 switches
void EncoderManagement(int EncClkPinNr, int EncDtPinNr, int JoyCcwButtonNr, int JoyCwButtonNr)
{
  int state_clk = digitalRead(EncClkPinNr);
   
  if ((state_enc_clk == LOW) && (state_clk == HIGH))   // Rotary encoder moved
  {     
    if (digitalRead(EncDtPinNr) == LOW)                // AntiClockWise move
    {      
      enc_position--;
      if ( enc_position < 0 ) {enc_position = ENC_STEP_NR;}
      Joystick.setButton(JoyCwButtonNr, false);
      Joystick.setButton(JoyCcwButtonNr, true);
      enc_timer = millis();
      DebugLn("Rotary encoder CounterClockWise, position " + String(enc_position));
    }
    else {                                             // ClockWise move
      enc_position++;
      if ( enc_position > ( ENC_STEP_NR - 1 ) ) {enc_position = 0;}
      Joystick.setButton(JoyCwButtonNr, true);
      Joystick.setButton(JoyCcwButtonNr, false);
      enc_timer = millis();

      DebugLn("Rotary encoder ClockWise, position " + String(enc_position));
    }
  }
  else {                                               // No move, wait for end of timer
    if((enc_timer + ENC_STRIKE_TIMER) < millis())
    {
      Joystick.setButton(JoyCwButtonNr, false);
      Joystick.setButton(JoyCcwButtonNr, false);
    }
  }
   
  state_enc_clk = state_clk;
} // End of "EncoderManagement"


//////////////////////////////////////////////////////////////////////////////////////////////
// Preparing all inputs of the PCF8574
void PreparePcfInputs(PCF8574* Pcf)
{
  DebugLn("Preparing PCF8574");
  Pcf->pinMode(P0, INPUT_PULLUP);
  Pcf->pinMode(P1, INPUT_PULLUP);
  Pcf->pinMode(P2, INPUT_PULLUP);
  Pcf->pinMode(P3, INPUT_PULLUP);
  Pcf->pinMode(P4, INPUT_PULLUP);
  Pcf->pinMode(P5, INPUT_PULLUP);
  Pcf->pinMode(P6, INPUT_PULLUP);
  Pcf->pinMode(P7, INPUT_PULLUP);
  Pcf->begin();
} // End of "PreparePcfInputs"


//////////////////////////////////////////////////////////////////////////////////////////////
// Debug texts to serial port (only if debug is active)
void DebugLn(String Msg)
{
  #ifdef DEBUG
  Serial.println(Msg);
  #endif // DEBUG
} // End of "DebugLn"


void DebugTxt(String Msg)
{
  #ifdef DEBUG
  Serial.print(Msg);
  #endif // DEBUG
} // End of "DebugTxt"


void DebugInit()
{
  #ifdef DEBUG
  Serial.begin(9600);
  delay(1000);
  // Display title
  Serial.println("");
  Serial.println("=== Control Panel - Black Otters ===");
  Serial.println("========== By Nem' & Rac' ==========");
  #endif // DEBUG
} // End of "DebugInit"

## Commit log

2021-06-03 Add : Inject initial List of hardware, 3D files, I/O wiring, Electrical Schematics, Sticker pattern, Arduino software.
    [CP-BO Back v15.f3d, CP-BO Back v15.stl, CP-BO Encoder locker v1.f3d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]
2021-06-03 Changed: Fix quantity of potentiometers.
    [CPBO Nomenclature.xlsx]
2021-06-04 Changed: Internationalization
    [CP-BO Back v15.f3d, CP-BO Back v15.stl, CP-BO Encoder locker v1.f3d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]
2021-06-04 Add instruction list.
    [Instructions listing.xlsx]
2021-11-06 Added: Explainations of addressing PCF8574 boards.
    [Hardware listing.xlsx, Instructions listing.xlsx]
2021-11-28 Changed: Fix bad pining of Arduino GND.
    [Electrical diagrams.fzz]
2021-11-28 Changed: Fix I/O assignments.
    [IO assignment.xlsx]
2021-11-28 Changed: Update instructions and hardware.
    [Hardware listing.xlsx, Instructions listing.xlsx]
2021-12-21 Added: Create a Tab for Joystick assignment simpler view.
    [IO assignment.xlsx]
2021-12-21 Changed: Add a debounce function on the 3 critical buttons (hardware wiring should be changed, but software can compensate).
2021-12-21 Added: Integrate a script to deploy the firmware without the full arduino IDE and compilation process for 1.1 version.
2021-12-21 Changed: Fix inverted switch logic.
    [ControlPanel.ino]
